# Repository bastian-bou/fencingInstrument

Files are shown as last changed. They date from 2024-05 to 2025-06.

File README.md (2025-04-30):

[][cc-by-nc-sa]

This work is licensed under a
[Creative Commons Attribution-NonCommercial-ShareAlike 4.0 International License][cc-by-nc-sa].

[][cc-by-nc-sa]

[cc-by-nc-sa]: http://creativecommons.org/licenses/by-nc-sa/4.0/
[cc-by-nc-sa-image]: https://licensebuttons.net/l/by-nc-sa/4.0/88x31.png
[cc-by-nc-sa-shield]: https://img.shields.io/badge/License-CC%20BY--NC--SA%204.0-lightgrey.svg

# Antiphona

This is an art project name Antiphona from the artist [Alexandra Riss](https://alexandra-riss.fr/).

It transforms the movements of a fencer during a fight into musical notes.
The fight becomes a unique music.

The device consists of two tripods on either side of the fencing piste.
Each tripod consists of 3 IR sensors spaced 50cm apart and an electronic interface PCB between an arduino micro and the 3 sensors.

## Hardware

IR Sensors are tfmini-s [datasheet](pj2-sj-pm-tfmini-s-a00-product-mannual-en-2155.pdf)

They need 5V DC power supply but the communication is through a LVTTL (3.3V) UART interface.

As the result, the PCB include a level shifter from 3.3V to 5V for the arduino and because the arduino will interrogate each sensor one after the other, there is a 3-way analog multiplexer for each communication channel (RX, TX).  
The PCB also include decoupling capacitors, as all components including sensors are powered by the 5V from the USB port on the arduino.

## Software

To communicate with sensors, I made my own library according to the datasheet with only the functionalities I needed and my specificities, which were:
- multipexer management,
- retrieval of values from the 3 lidars,
- selection of the right value on the 3 sensors

Every 20ms we interrogate the sensors, and play a MIDI note on the USB interface only if a new valid distance is received.  
The MIDI note is played as a function of distance and relative speed. Each meter on the track corresponds to a note from C3 to B4, and the speed (as a function of the distance separating the old value from the new one) corresponds to the velocity of the note.

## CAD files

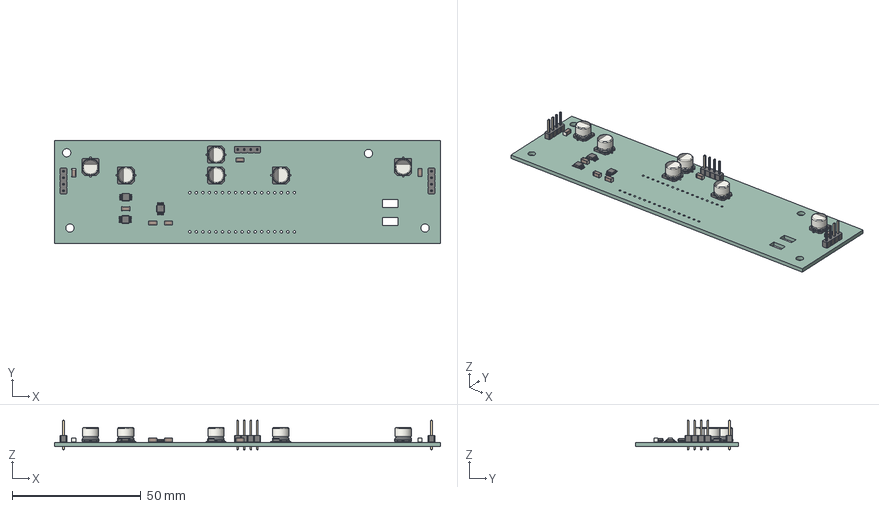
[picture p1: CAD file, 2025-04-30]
Hardware/interface/interface.step
150.0 x 40.0 x 11.5 mm
CP_Elec_63x57 x 6
C_1206_3216Metric x 6
PinHeader_1x04_P254mm_Vertical x 3
VSSOP_8_30x30mm_P065mm x 2
TSSOP_8_3x3mm_P065mm
interface_PCB

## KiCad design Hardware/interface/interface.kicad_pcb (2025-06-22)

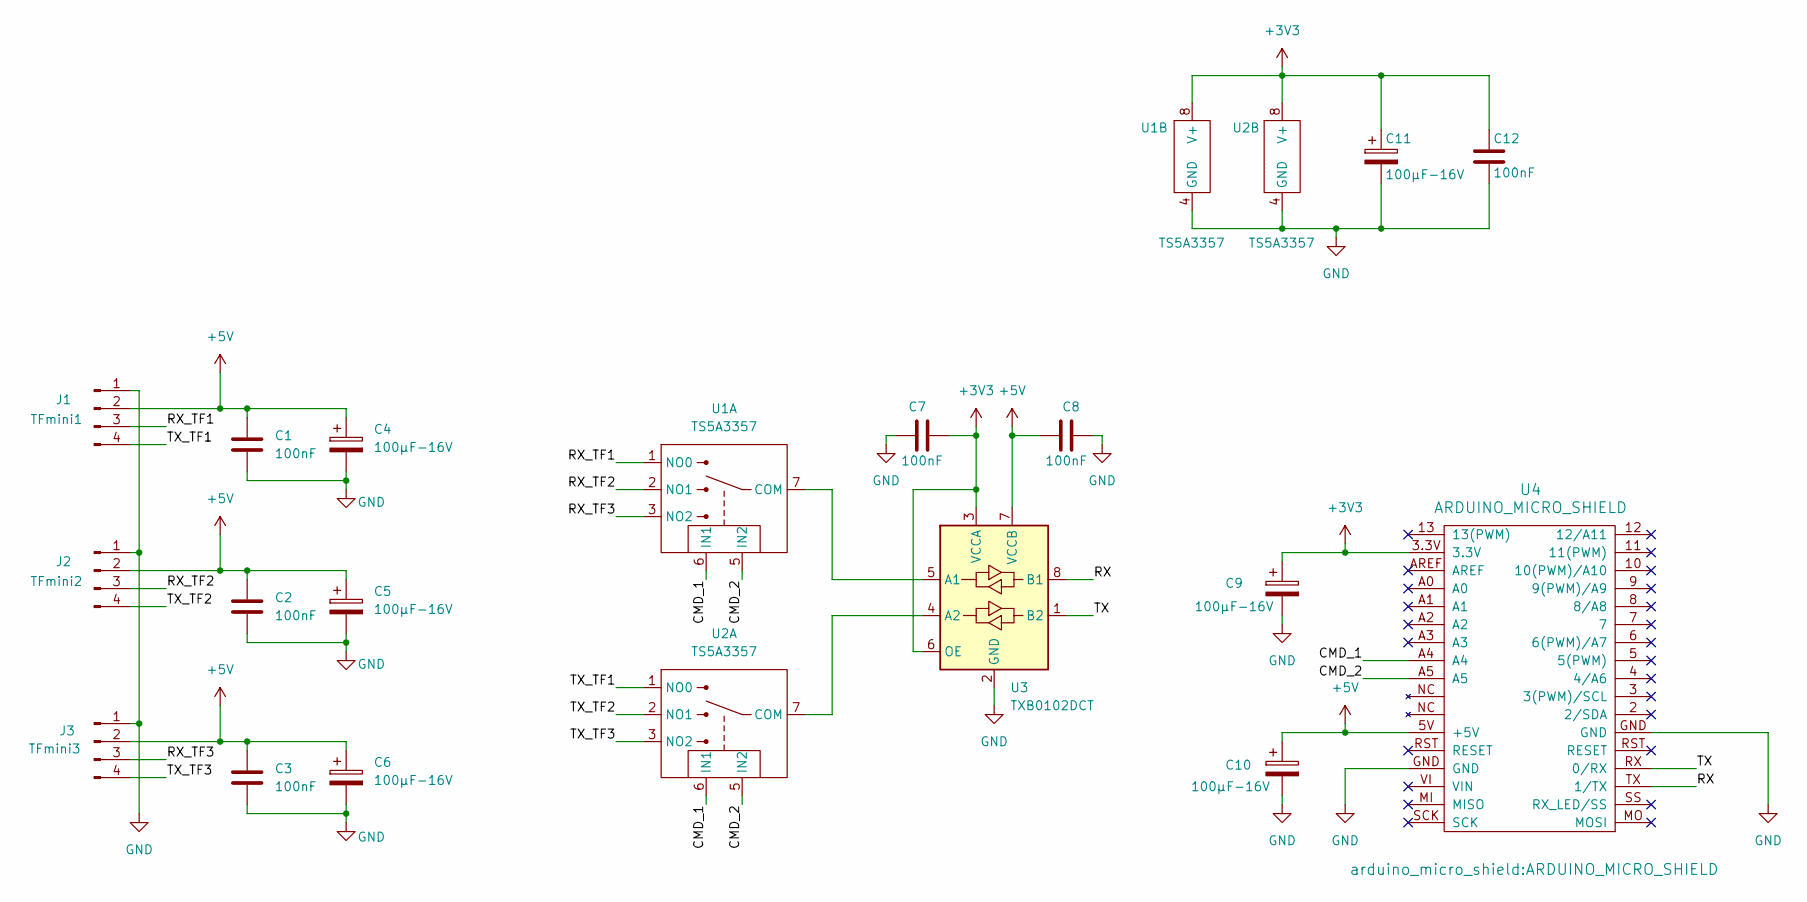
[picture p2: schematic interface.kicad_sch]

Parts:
C1, C2, C3, C7, C8, C12: 100nF; C_1206_3216Metric_Pad1.33x1.80mm_HandSolder
C4, C5, C6, C9, C10, C11: 100µF-16V; CP_Elec_6.3x5.7
J1: TFmini1; SolderWire-0.1sqmm_1x04_P3.6mm_D0.4mm_OD1mm_Relief
J2: TFmini2; SolderWire-0.1sqmm_1x04_P3.6mm_D0.4mm_OD1mm_Relief
J3: TFmini3; SolderWire-0.1sqmm_1x04_P3.6mm_D0.4mm_OD1mm_Relief
U1, U2: TS5A3357; VSSOP-8_3.0x3.0mm_P0.65mm
U3: TXB0102DCT; TSSOP-8_3x3mm_P0.65mm
U4: ARDUINO_MICRO_SHIELD

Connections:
+3V3: C7.1, C9.1, C11.1, C12.1, U1.8 (V+), U2.8 (V+), U3.3 (VCCA), U3.6 (OE), U4.3.3V
+5V: C1.1, C2.1, C3.1, C4.1, C5.1, C6.1, C8.1, C10.1, J1.2, J2.2, J3.2, U3.7 (VCCB), U4.5V (+5V)
/CMD_1: U1.6 (IN1), U2.6 (IN1), U4.A4
/CMD_2: U1.5 (IN2), U2.5 (IN2), U4.A5
/RX: U3.8 (B1), U4.TX (1/TX)
/RX_TF1: J1.3, U1.1 (NO0)
/RX_TF2: J2.3, U1.2 (NO1)
/RX_TF3: J3.3, U1.3 (NO2)
/TX: U3.1 (B2), U4.RX (0/RX)
/TX_TF1: J1.4, U2.1 (NO0)
/TX_TF2: J2.4, U2.2 (NO1)
/TX_TF3: J3.4, U2.3 (NO2)
GND: C1.2, C2.2, C3.2, C4.2, C5.2, C6.2, C7.2, C8.2, C9.2, C10.2, C11.2, C12.2, J1.1, J2.1, J3.1, U1.4 (GND), U2.4 (GND), U3.2 (GND), U4.GND
unnamed: U1.7 (COM), U3.5 (A1)
unnamed: U2.7 (COM), U3.4 (A2)

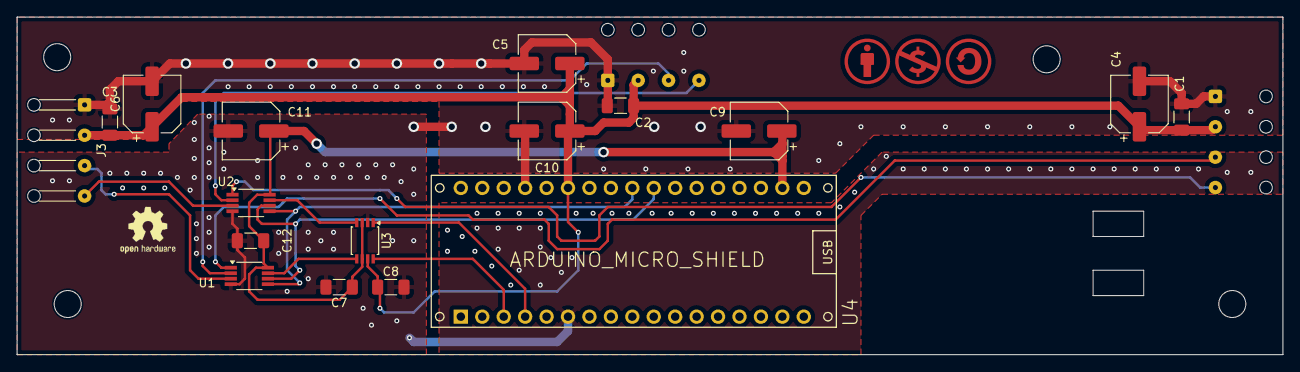
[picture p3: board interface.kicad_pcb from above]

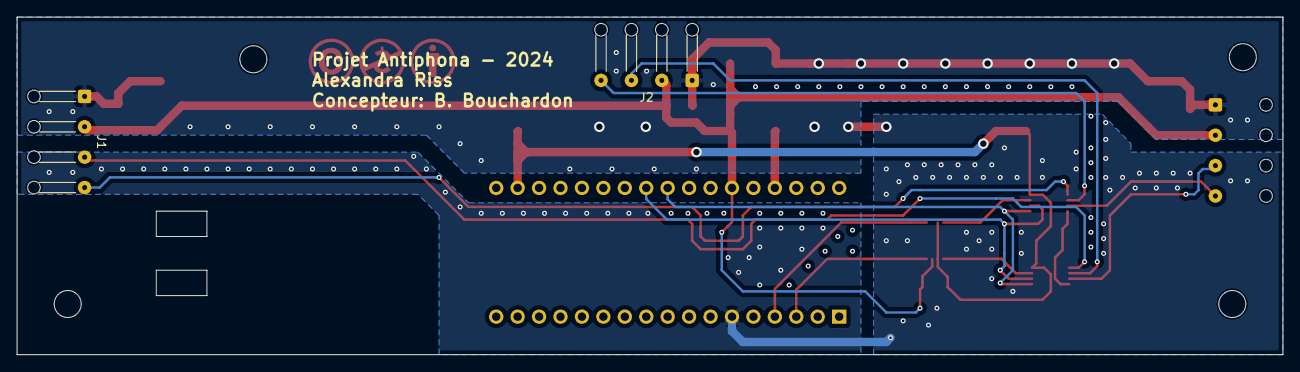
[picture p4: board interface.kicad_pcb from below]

Board: 2 copper layers, 150.0 x 40.0 mm, 19 parts (2 on the bottom side), 15 nets.

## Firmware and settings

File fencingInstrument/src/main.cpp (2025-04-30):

/**
 * @file main.cpp
 * @author B. Bouchardon
 * @brief 
 * @version 2.0
 * @date 2024-03-15
 * 
 */
#include "main.h"

/** Time between two measures (ms) */
#define FRAME_RATE_MS 100
/** Midi channel to communicate on USB */
#define MIDI_CHANNEL 0

lidar sensors(100);

void setup()
{
  pinMode(LED_BUILTIN, OUTPUT);
  digitalWrite(LED_BUILTIN, LOW);

#ifdef DEBUG
  // Step 1: Initialize hardware serial port (serial debug port)
  Serial.begin(9600);
  // wait for serial port to connect. Needed for native USB port only
  while (!Serial);
     
  DEBUG_PRINTLN("Initializing...");

#endif

  // Initialise
  sensors.begin();

  DEBUG_PRINTLN("Initialized");
}


void loop()
{
  // Wait some time before taking the next measurement. Match this with your frame rate.
  uint16_t newDistance = sensors.get_n_compute();
  if (newDistance != UINT16_MAX) {
    play_note(newDistance);
  }
  delay(20);
}

void play_note(uint16_t newDistance)
{
  uint8_t lastPositionNote = (uint8_t)(sensors.m_last_choosed_dist / 100);
  uint8_t newPositionNote = (uint8_t)(newDistance / 100);
  uint16_t distance = (uint16_t) (abs(sensors.m_last_choosed_dist - newDistance));
  uint8_t velocity = (uint8_t) (map(distance, HYST_CM, 100, 64, 127));

  DEBUG_PRINT("Position note: ");
  DEBUG_PRINT(newPositionNote);
  DEBUG_PRINT(", Velocity note: ");
  DEBUG_PRINTLN(velocity);
  #ifndef NO_MIDI
    note_on(MIDI_CHANNEL, notePitches[newPositionNote], velocity);
    if (lastPositionNote != newPositionNote) {
      note_off(MIDI_CHANNEL, notePitches[lastPositionNote], 0);
    }
    // Send MIDI data to USB
    MidiUSB.flush();
  #endif

  sensors.m_last_choosed_dist = newDistance;
}

#ifndef NO_MIDI

void note_on(byte channel, byte pitch, byte velocity)
{
  midiEventPacket_t noteOn = {0x09, (uint8_t)(0x90 | channel), pitch, velocity};
  MidiUSB.sendMIDI(noteOn);
}


void note_off(byte channel, byte pitch, byte velocity)
{
  midiEventPacket_t noteOff = {0x08, (uint8_t)(0x80 | channel), pitch, velocity};
  MidiUSB.sendMIDI(noteOff);
}
#endif

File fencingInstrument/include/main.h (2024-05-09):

/**
 * @file main.h
 * @author B. Bouchardon
 * @brief 
 * @version 0.1
 * @date 2022-09-21
 * 
 */

#include <Arduino.h>
#include <lidar.hpp>

#ifndef NO_MIDI
#include "MIDIUSB.h"
#include "pitchToNote.h"
#endif

#define DURATION_ROW 4
#define NUM_NOTES 14

enum error_type {
    LIDAR_TEMP_TOO_HIGH = 0,
    LIDAR_COMM_ERROR,
    MIDI_ERROR,
    NO_ERROR
};

uint16_t duration_error[DURATION_ROW][2] = {
    {error_type::LIDAR_TEMP_TOO_HIGH, 50},
    {error_type::LIDAR_COMM_ERROR, 250},
    {error_type::MIDI_ERROR, 500},
    {error_type::NO_ERROR, 0}
};

struct LedStatus {
    uint8_t led_num;
    uint16_t duration_row;

    unsigned long last_millis;
    bool led_state;

    LedStatus()
    {
        LedStatus(LED_BUILTIN);
    }

    LedStatus(uint8_t ledNum)
    {
        last_millis = 0;
        led_state = true;
        setRowDurationError(error_type::NO_ERROR);
        pinMode(led_num = ledNum, OUTPUT);
        digitalWrite(led_num, HIGH);
    }

    void setRowDurationError(error_type error)
    {
        for (int i = 0; i < DURATION_ROW; i++)
        {
            if (duration_error[i][0] == error)
            {
                duration_row = i;
                break;
            }
        }
    }

    void updateStatus()
    {
        // if we have a duration to blink
        if (duration_error[duration_row][1] != 0)
        {
            unsigned long currentMillis = millis();

            if ((currentMillis - last_millis) >= duration_error[duration_row][1])
            {
                last_millis = currentMillis;
                led_state = !led_state;
                digitalWrite(led_num, led_state);
            }
        }
    }

};

#ifndef NO_MIDI
// list of notes to play at each meter
const byte notePitches[NUM_NOTES] = {pitchC3, pitchD3, pitchE3, pitchF3, pitchG3, pitchA3, pitchB3, pitchC4, pitchD4, pitchE4, pitchF4, pitchG4, pitchA4, pitchB4};
#endif

/**
 * @brief Convert the distance and play a note
 * 
 * @param[in] newDistance The new distance
*/
void play_note(uint16_t newDistance);

/**
 * @brief Set a MIDI note
 * 
 * @param[in] channel Channel number to communicate
 * @param[in] pitch Note to play
 * @param[in] velocity The force with which you press the note
 */
void note_on(byte channel, byte pitch, byte velocity);

/**
 * @brief Unset a MIDI note
 * 
 * @param[in] channel Channel number to communicate
 * @param[in] pitch Note to unplay
 * @param[in] velocity The force with which you press the note (not mandatory)
 */
void note_off(byte channel, byte pitch, byte velocity);

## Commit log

2022-08-31 add libs, testing complet on lidar, starting implementation of MIDI
2022-08-31 add debug, add different boards, add midi note, debug is running
2024-04-20 add all current work on embedded code and add PCB interface for 3 lidars
    [interface.kicad_pcb, interface.kicad_sch]
2024-04-20 Almost finish PCB routing
    [interface.kicad_pcb, interface.kicad_sch]
2024-04-21 PCB finished and update gitignore with kicad files
    [interface.kicad_pcb]
2024-04-24 Add html bom
2024-05-09 Remove TF-mini library, tested with 3 lidar
2025-04-30 Add stuff in README Commit new changes on software from Victor Hugo on may 2024 Add tfminis datasheet
    [interface.step]
2025-06-22 Change sensor connectors to be more strong, efficient
    [interface.kicad_pcb, interface.kicad_sch]

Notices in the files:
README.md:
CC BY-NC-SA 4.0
